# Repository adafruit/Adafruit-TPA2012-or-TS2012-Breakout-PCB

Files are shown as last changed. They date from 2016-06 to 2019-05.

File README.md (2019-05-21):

## Adafruit TPA2012 or TS2012 Breakout PCB
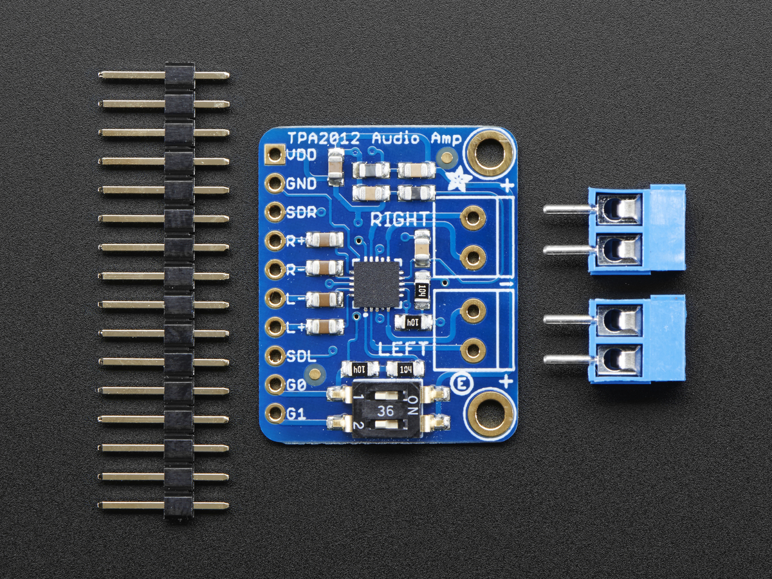
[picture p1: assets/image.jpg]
<a href="http://www.adafruit.com/products/1552"><br/>
Click here to purchase one from the Adafruit shop</a>

This incredibly small stereo amplifier is surprisingly powerful - able to deliver 2 x 2.1W channels into 4 ohm impedance speakers (@ 10% THD). Inside the miniature chip is a class D controller, able to run from 2.7V-5.5VDC. Since the amp is a class D, it's incredibly efficient (89% efficient when driving an 8Ω speaker at 1.5 Watt) - making it perfect for portable and battery-powered projects. It has built in thermal and over-current protection but we could barely tell it got hot. This board is a welcome upgrade to basic "LM386" amps!

The inputs of the amplifier go through 1.0uF capacitors, so they are fully 'differential' - if you don't have differential outputs, simply tie the R- and L- to ground. The outputs are "Bridge Tied" - that means they connect directly to the outputs, no connection to ground. The output is a ~300KHz square wave PWM that is then 'averaged out' by the speaker coil - the high frequencies are not heard. All the above means that you can't connect the output into another amplifier, it should drive the speakers directly.

Comes with a fully assembled and tested breakout board with 1.0uF input capacitors. We also include a dual mini DIP switch for setting the amplifier gain on the fly, 3.5mm screw-terminal blocks so you can easily attach/detach your speakers, and some header in case you want to plug it into a breadboard. You will be ready to rock in 15 minutes!

PCB files for the Adafruit TPA2012 or TS2012 Stereo Class-D Audio Amp Breakout. The format is EagleCAD schematic and board layout
- https://www.adafruit.com/product/1552

### License

Adafruit invests time and resources providing this open source design, please support Adafruit and open-source hardware by purchasing products from [Adafruit](https://www.adafruit.com)!

All text above must be included in any redistribution

Designed by Limor Fried/Ladyada for Adafruit Industries.
Creative Commons Attribution/Share-Alike, all text above must be included in any redistribution. 
See license.txt for additional information.

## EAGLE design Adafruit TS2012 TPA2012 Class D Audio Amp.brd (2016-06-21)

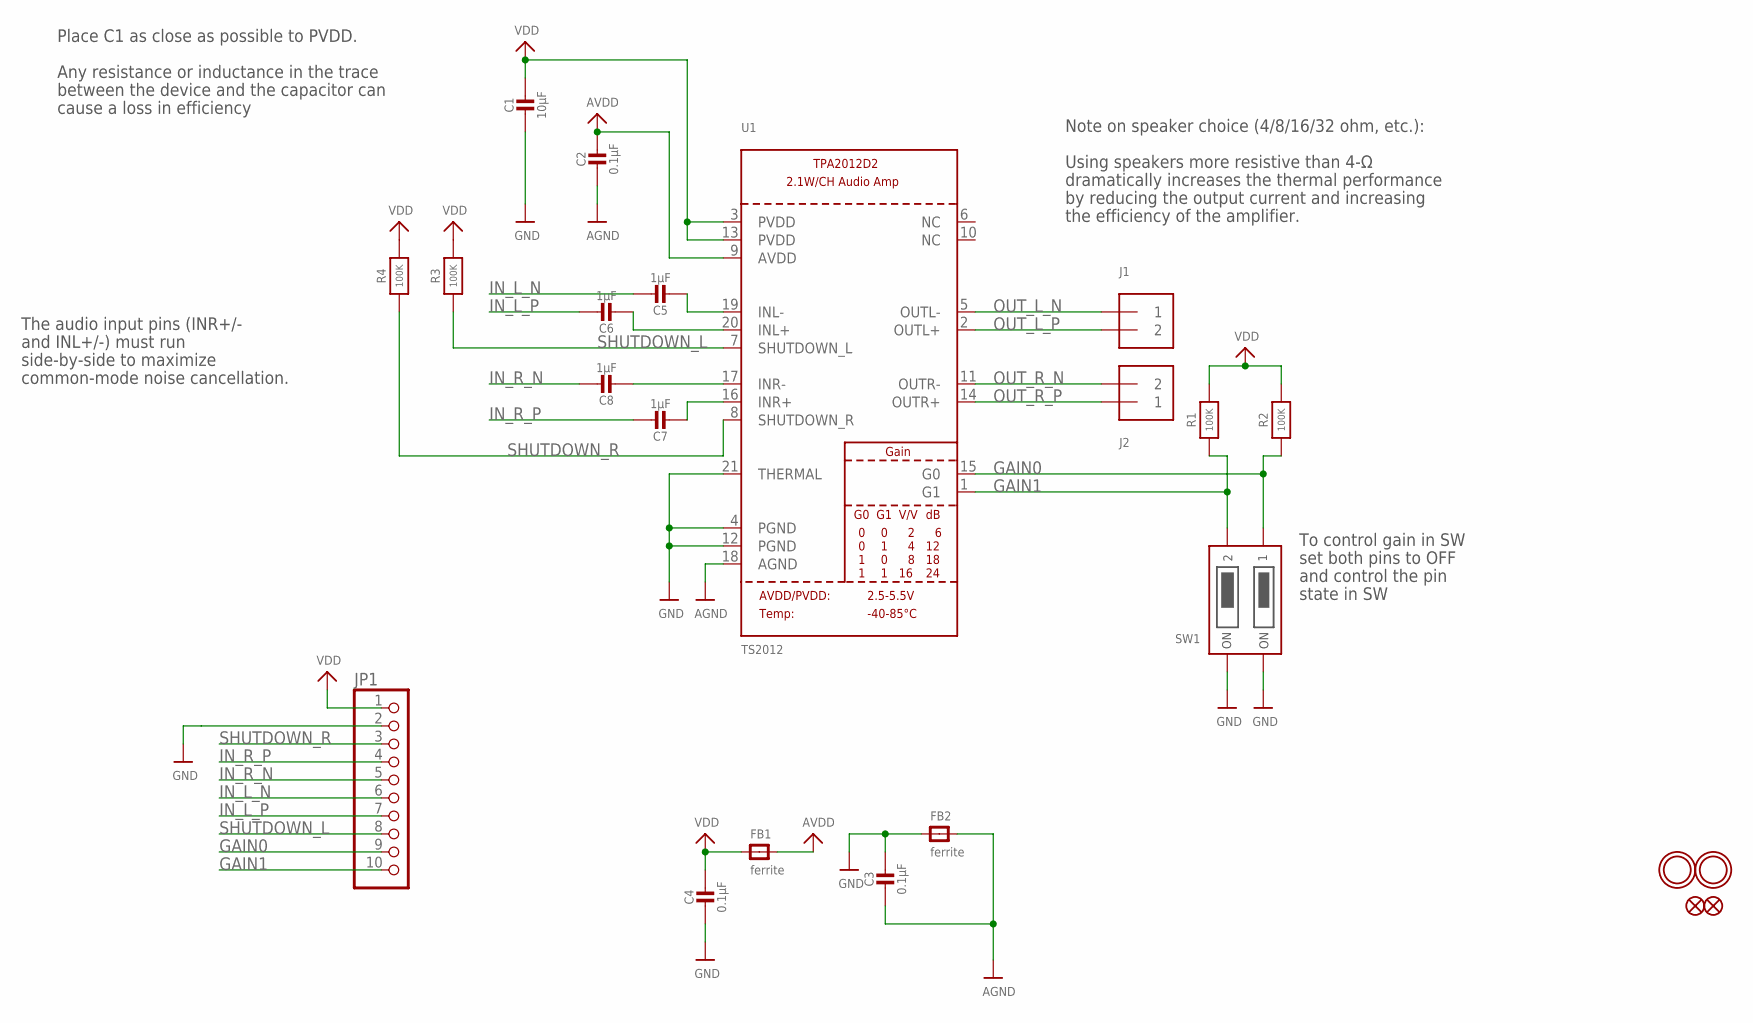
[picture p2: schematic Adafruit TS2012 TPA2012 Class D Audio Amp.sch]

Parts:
C1: 10µF; _0805MP
C2, C3, C4: 0.1µF; _0805MP
C5, C6, C7, C8: 1µF; _0805MP
FB1, FB2: ferrite; _0805MP
FID1, FID2: FIDUCIAL""; FIDUCIAL_1MM
J1, J2: TERMBLOCK_1X2; TERMBLOCK_1X2-3.5MM
JP1: HEADER-1X1070MIL; 1X10_ROUND70
R1, R2, R3, R4: 100K; _0805MP
SW1: DIPSWITCH_2PIN
U1: TS2012; WQFN20
U$20, U$21: MOUNTINGHOLE2.5_THICK; MOUNTINGHOLE_2.5_PLATED_THICK

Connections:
AGND: C2.2, C3.2, FB2.2, U1.18 (AGND)
AVDD: C2.1, FB1.2, U1.9 (AVDD)
GAIN0: JP1.9, R2.1, SW1.1OFF, U1.15 (G0)
GAIN1: JP1.10, R1.1, SW1.2OFF, U1.1 (G1)
GND: C1.2, C3.1, C4.2, FB2.1, JP1.2, SW1.1ON, SW1.2ON, U1.4 (PGND), U1.12 (PGND), U1.21 (THERMAL)
IN_L_N: C5.1, JP1.6
IN_L_P: C6.1, JP1.7
IN_R_N: C8.1, JP1.5
IN_R_P: C7.1, JP1.4
unnamed: C6.2, U1.20 (INL+)
unnamed: C5.2, U1.19 (INL-)
unnamed: C8.2, U1.17 (INR-)
unnamed: C7.2, U1.16 (INR+)
OUT_L_N: J1.1, U1.5 (OUTL-)
OUT_L_P: J1.2, U1.2 (OUTL+)
OUT_R_N: J2.2, U1.11 (OUTR-)
OUT_R_P: J2.1, U1.14 (OUTR+)
SHUTDOWN_L: JP1.8, R3.1, U1.7 (SHUTDOWN_L)
SHUTDOWN_R: JP1.3, R4.1, U1.8 (SHUTDOWN_R)
VDD: C1.1, C4.1, FB1.1, JP1.1, R1.2, R2.2, R3.2, R4.2, U1.3 (PVDD), U1.13 (PVDD)

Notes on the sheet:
To control gain in SW
set both pins to OFF
and control the pin
state in SW
Place C1 as close as possible to PVDD.
Any resistance or inductance in the trace
between the device and the capacitor can
cause a loss in efficiency
Using speakers more resistive than 4-Ω
dramatically increases the thermal performance
by reducing the output current and increasing
the efficiency of the amplifier.
Note on speaker choice (4/8/16/32 ohm, etc.):
The audio input pins (INR+/-
and INL+/-) must run
side-by-side to maximize
common-mode noise cancellation.

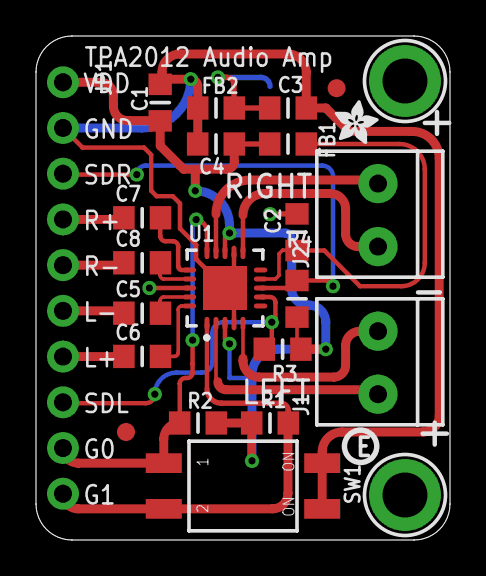
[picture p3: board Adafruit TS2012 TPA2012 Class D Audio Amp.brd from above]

Board: 2 copper layers, 23.0 x 28.0 mm, 25 parts (0 on the bottom side), 20 nets.

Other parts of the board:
U$22: ADAFRUIT_2.5MM
U$23: PCBFEAT-REV-040
